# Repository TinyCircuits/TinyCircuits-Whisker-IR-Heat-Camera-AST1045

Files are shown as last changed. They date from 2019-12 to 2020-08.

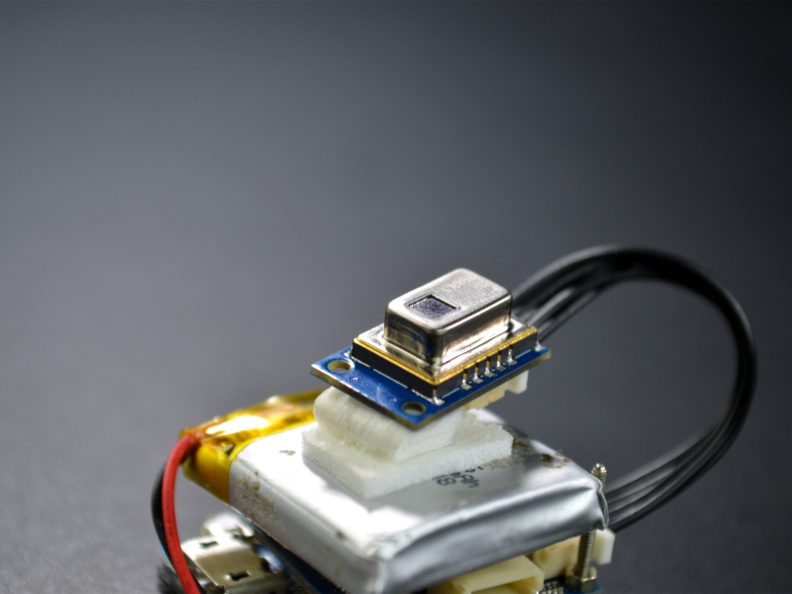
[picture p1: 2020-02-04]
images/AST1045-Tutorial-Image-01.jpg

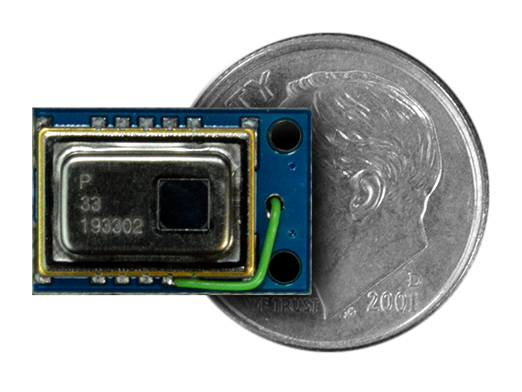
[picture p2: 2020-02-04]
images/AST1045-Product-Picture-03.png

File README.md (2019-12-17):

# TinyCircuits-Wireling-IR-Heat-Camera-AST1045
# Rev 1

The design files are located under design_files/ for the TinyCircuits AST1045 Rev 1 PCB. This is a Wireling board which features an IR thermal Camera using the AMG8833 IR Array Gird-EYE Sensor.
Format is in Cadsoft Eagle format - Eagle version 6.2 was used for the original design.

For more infomation on this, check out the product page at TinyCircuits.com

# License:

Design by TinyCircuits.
All design files are released under the Creative Commons Attribution Share-Alike 3.0 License, see the following link for details: http://creativecommons.org/licenses/by-sa/3.0

All text above must be included in any redistribution or derived design

This project uses designs and concepts developed as part of the Arduino project and the LilyPad project.  The TinyCircuits design files themselves (schematics, PCB and libraries) are not directly derived from these works' design files and have been created new, however the concepts and basic architecture behind the TinyDuino and TinyLily products are derived and we thank the hard work of the organizations below for their contributions to open-source hardware:
  
Original Arduino Uno Design by Team Arduino

LilyPad Arduino Design by Leah Buechley and Sparkfun Electronics

Please support the open-source hardware community

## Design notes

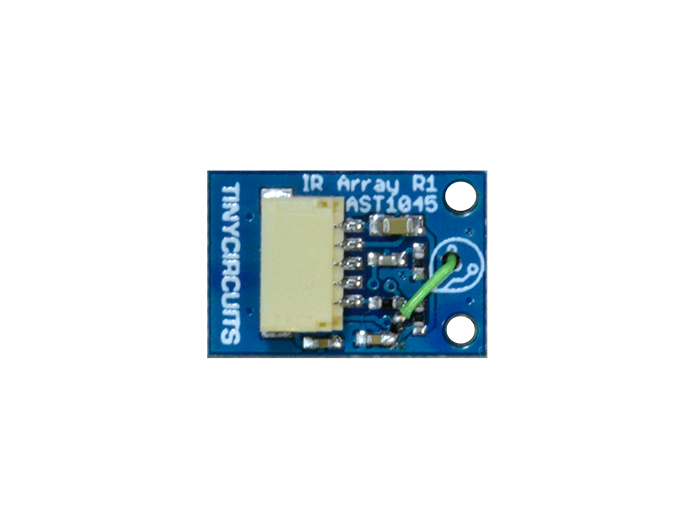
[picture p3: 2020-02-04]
images/AST1045-Product-Picture-02.png

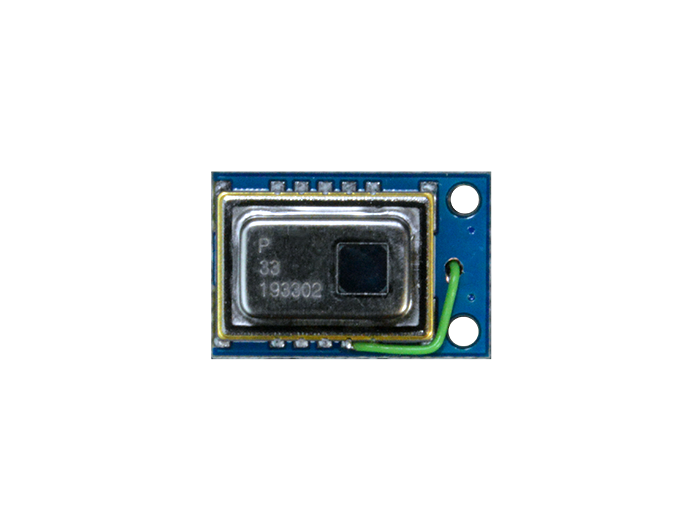
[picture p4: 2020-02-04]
images/AST1045-Product-Picture-01.png

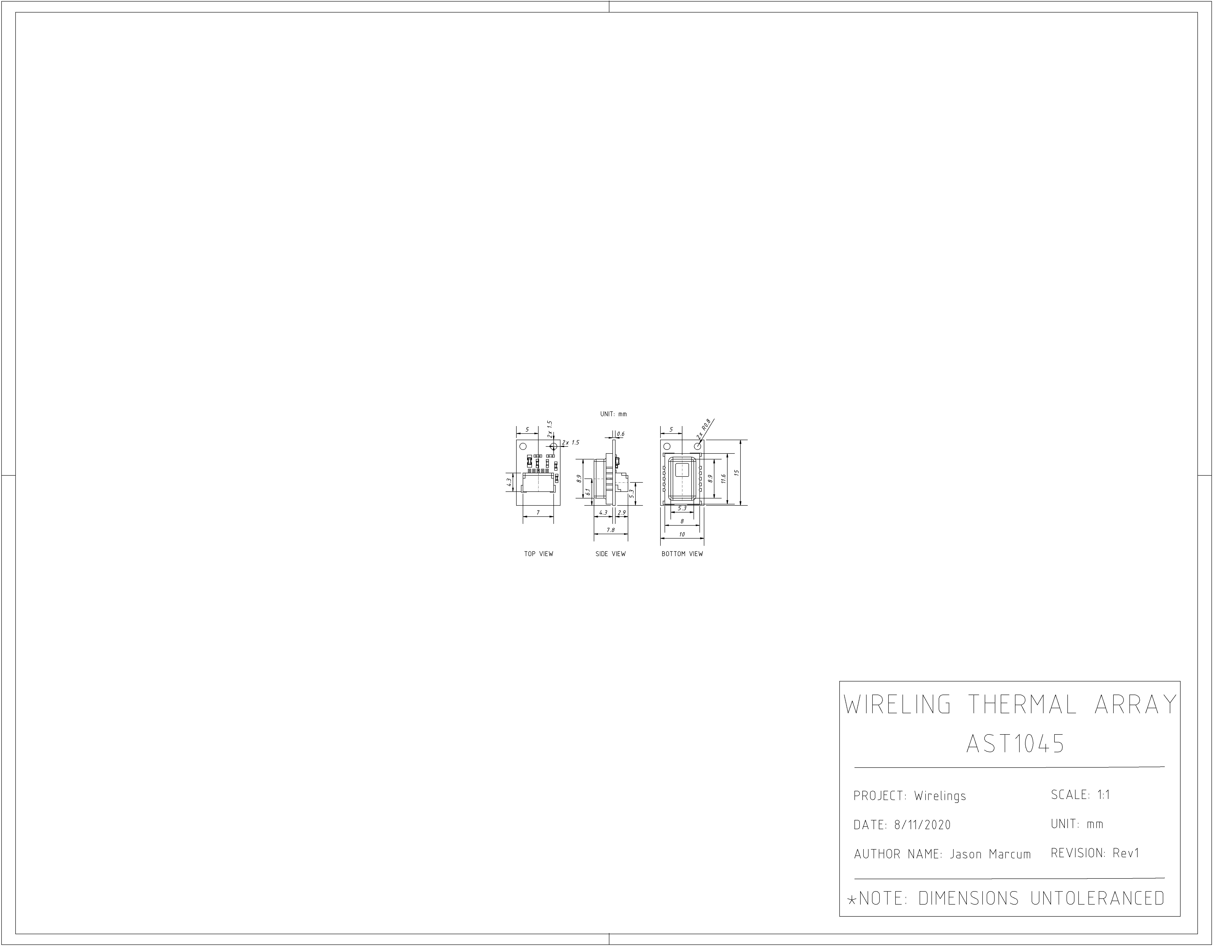
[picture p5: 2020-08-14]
cad/Wireling_THRMERAL_AST1045_REV1-DETAILED_DRAWING-PNG.png

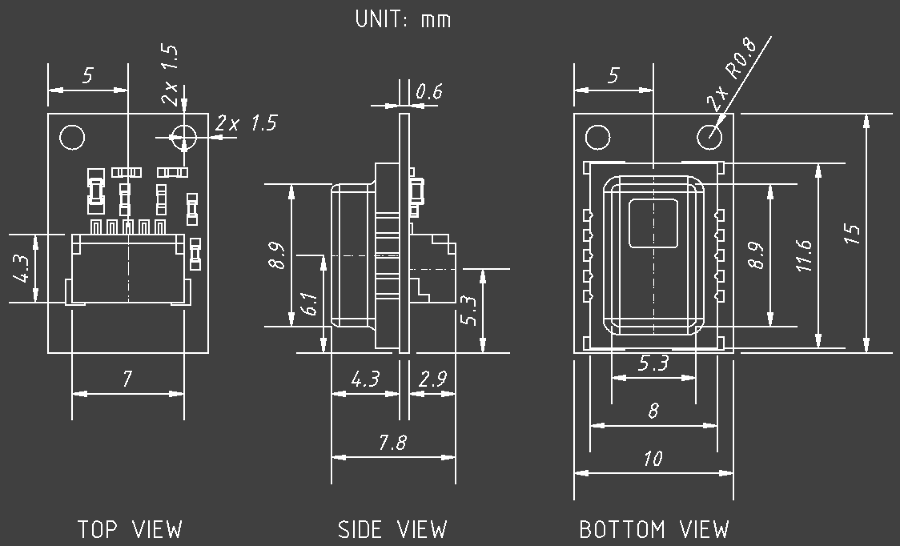
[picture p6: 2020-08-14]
cad/Wireling_THRMERAL_AST1045_REV1-DETAILED_DRAWING_COMPACT-PNG.png

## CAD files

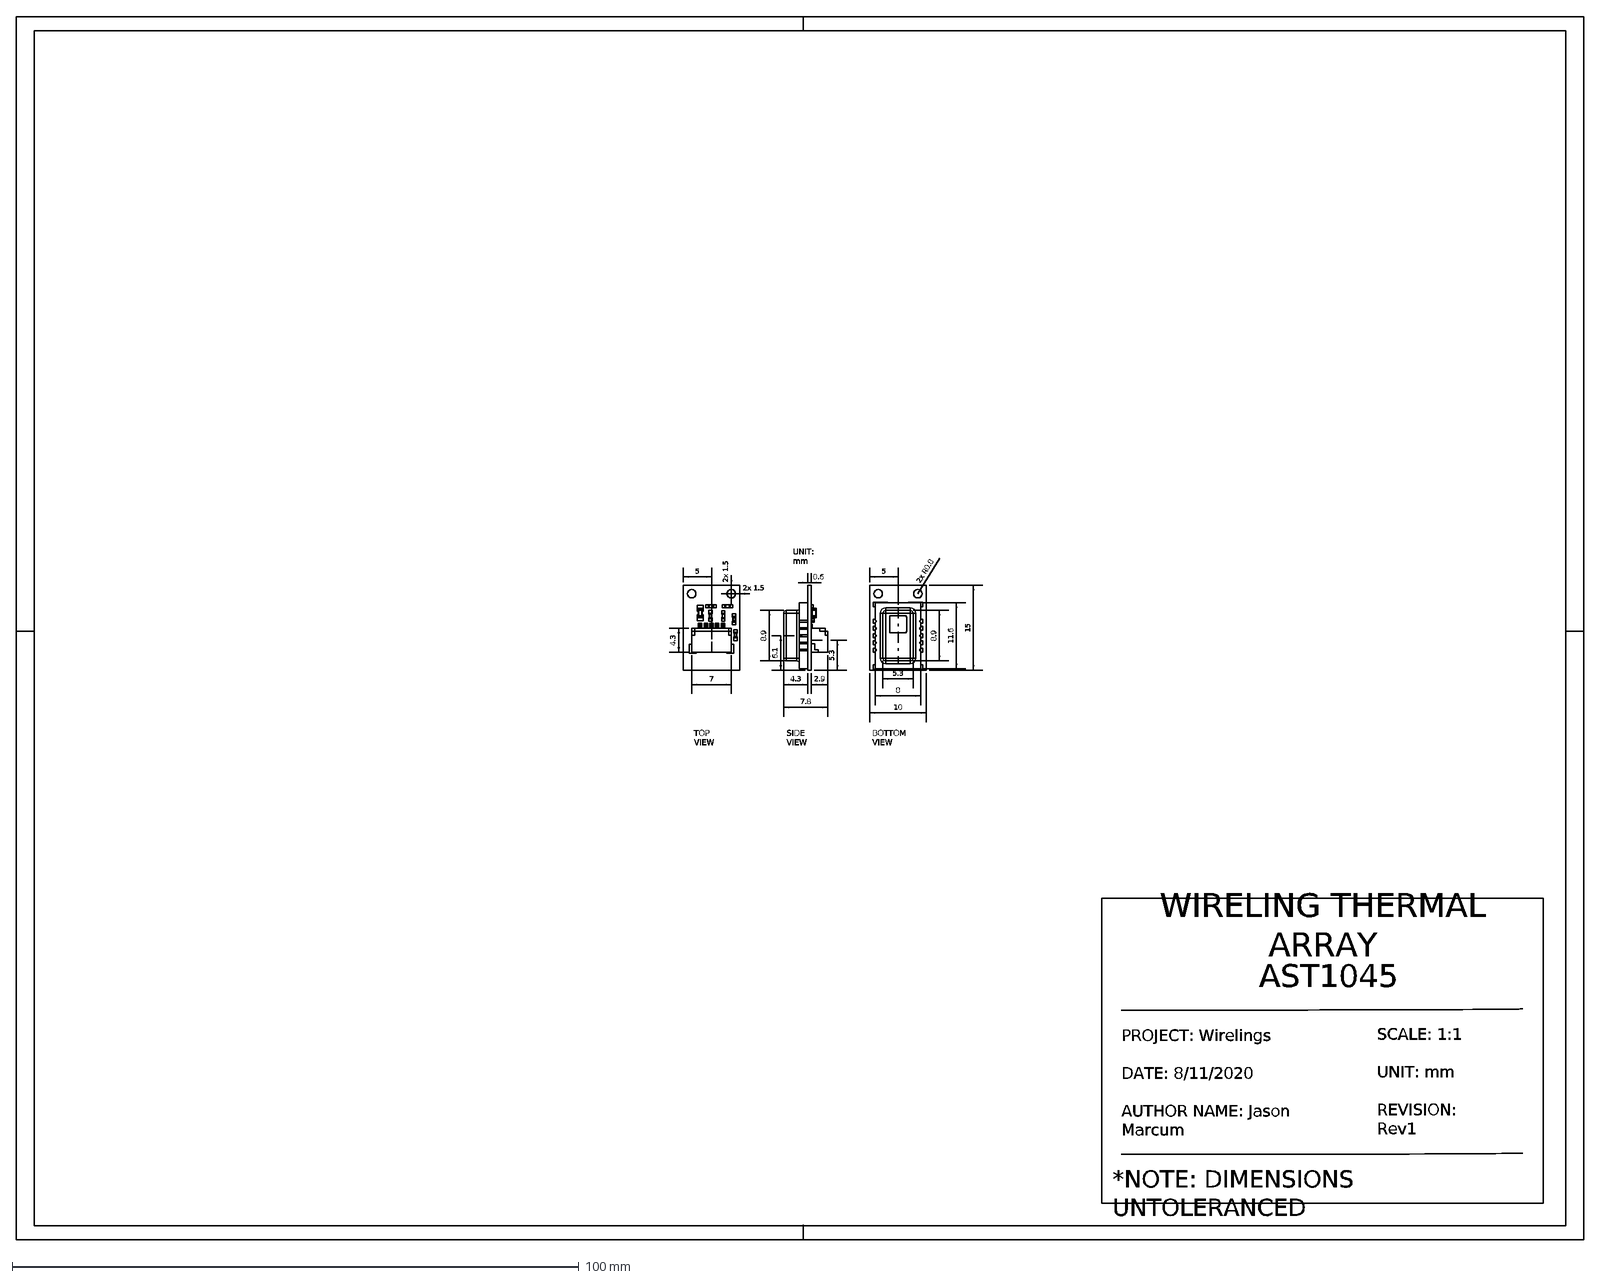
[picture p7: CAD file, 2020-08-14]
cad/Wireling_THRMERAL_AST1045_REV1-DETAILED_DRAWING-DXF.dxf
*NOTE: DIMENSIONS UNTOLERANCED
SCALE: 1:1 UNIT: mm REVISION: Rev1
5.3
6.1
2.9
4.3
0.6
SIDE VIEW
WIRELING THERMAL ARRAY
AST1045
PROJECT: Wirelings DATE: 8/11/2020 AUTHOR NAME: Jason Marcum
7.8
8.9
5
7
TOP VIEW
2x 1.5
8
11.6
15
10
BOTTOM VIEW
2x R0.8
UNIT: mm

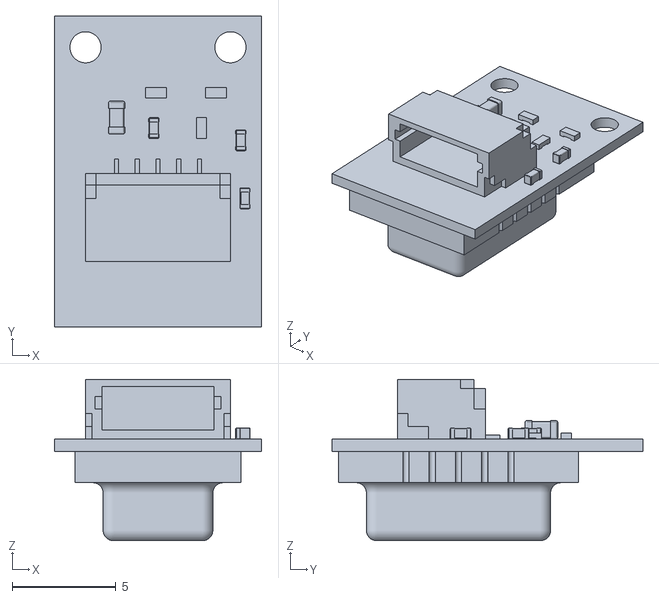
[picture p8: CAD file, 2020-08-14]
cad/Wireling_THRMERAL_AST1045_REV1-STL.stl
10.0 x 15.0 x 7.80

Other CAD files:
cad/Wireling_THRMERAL_AST1045_REV1-IGES.iges

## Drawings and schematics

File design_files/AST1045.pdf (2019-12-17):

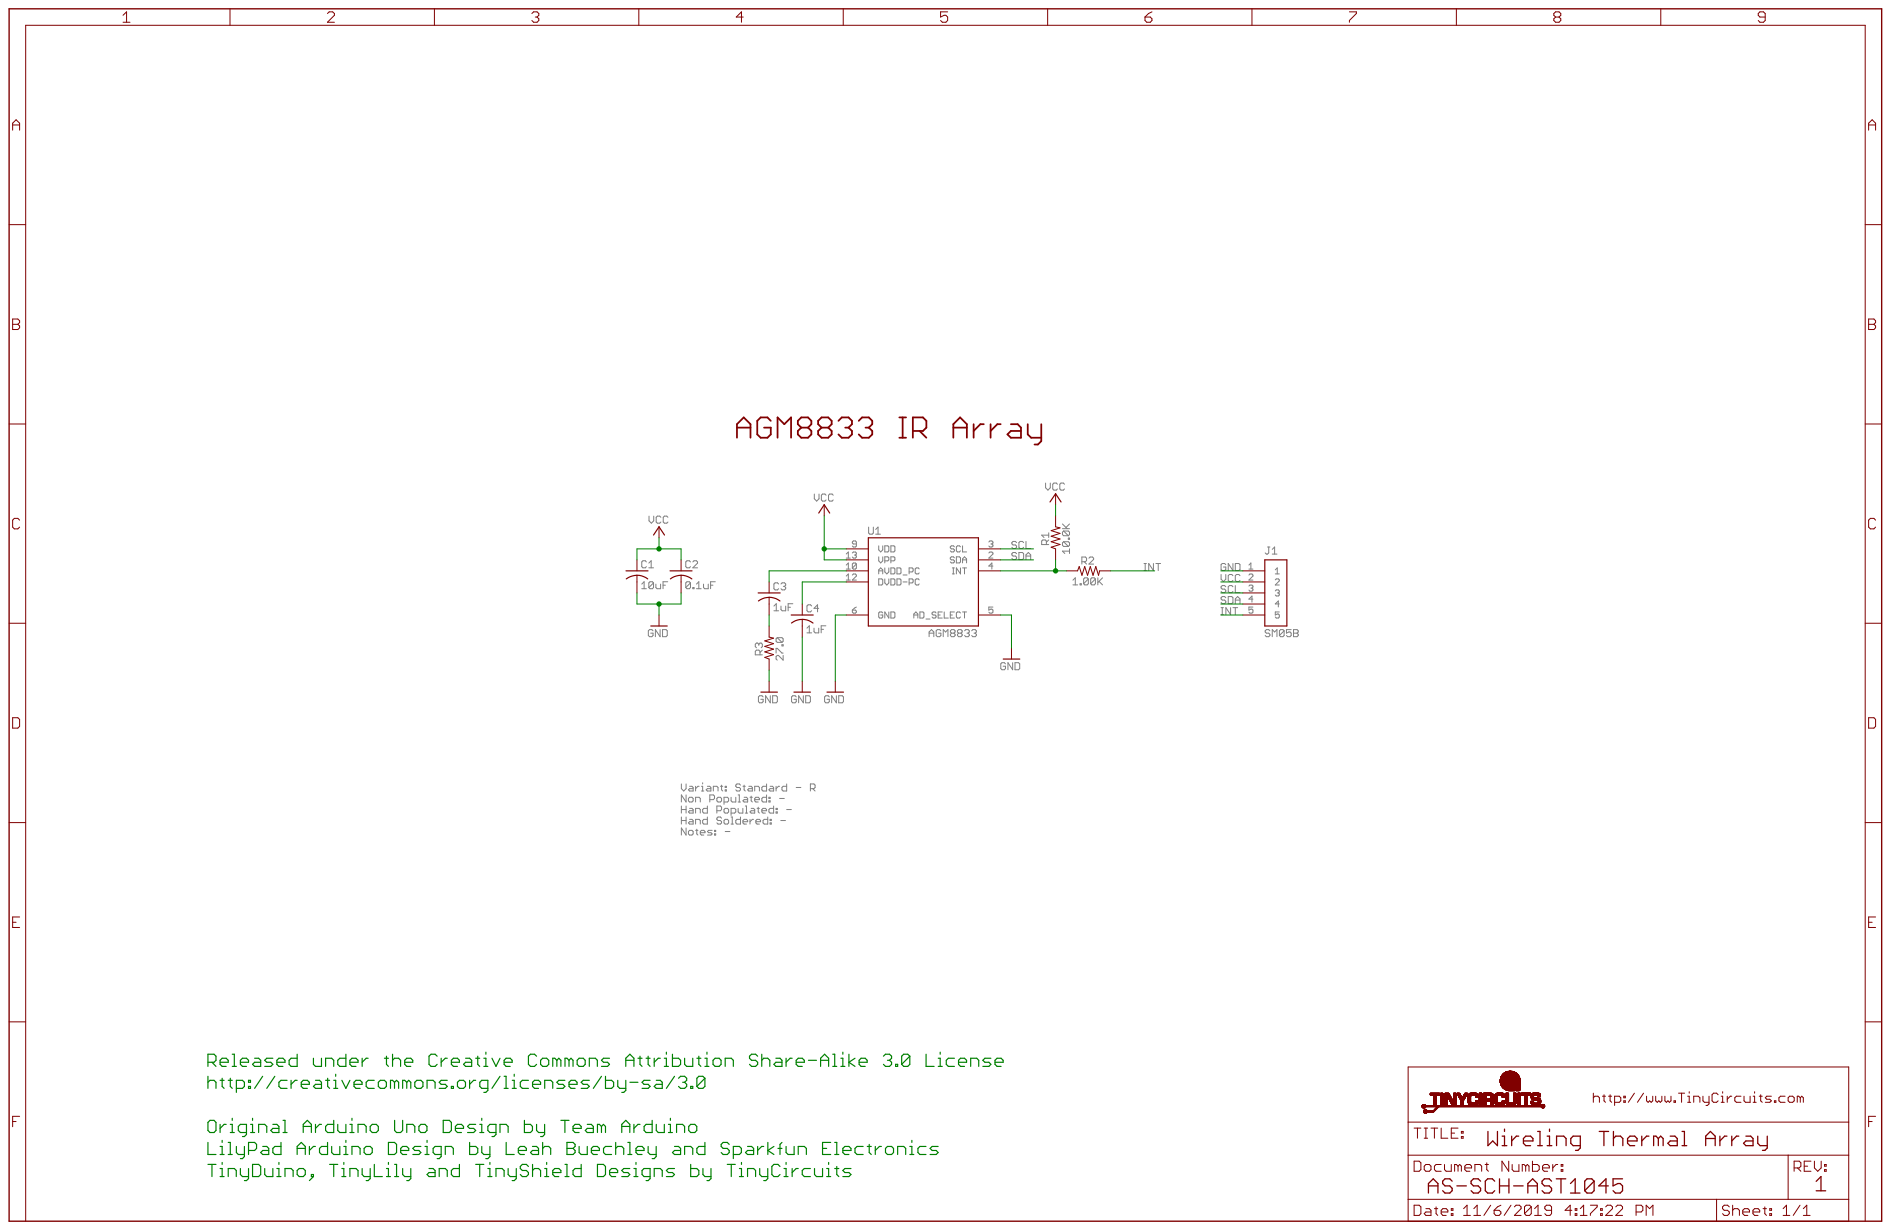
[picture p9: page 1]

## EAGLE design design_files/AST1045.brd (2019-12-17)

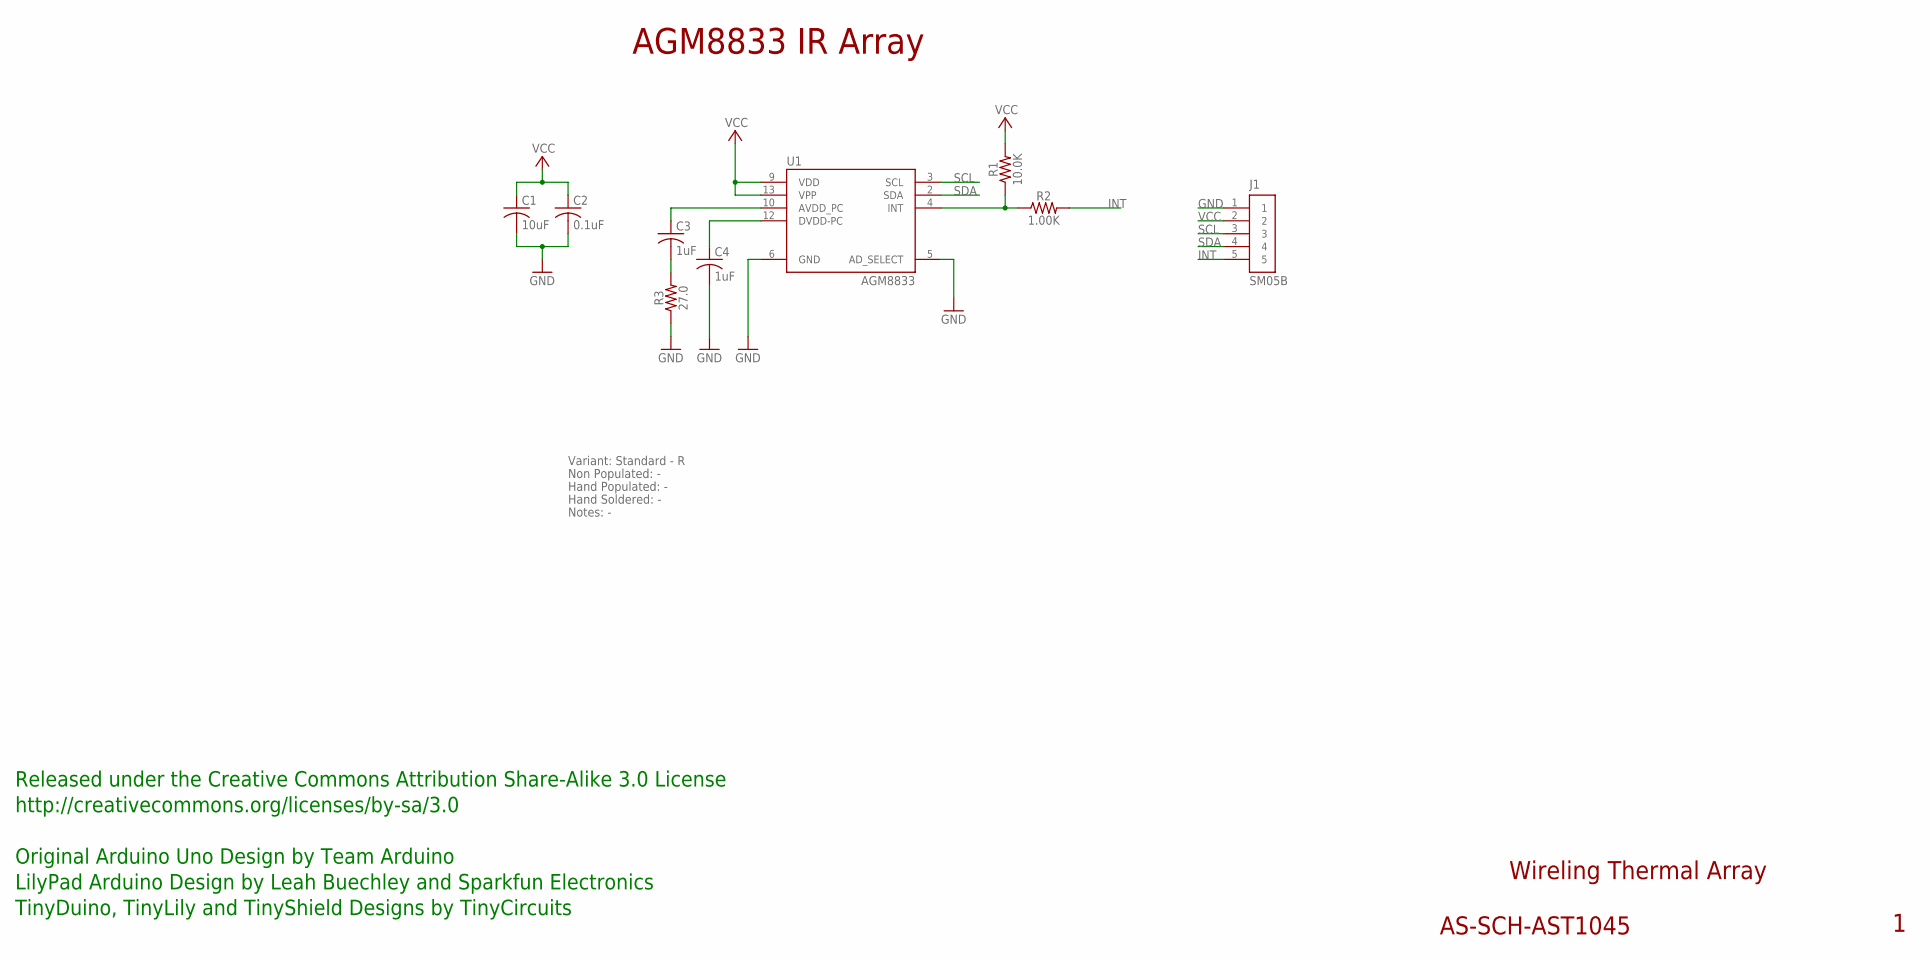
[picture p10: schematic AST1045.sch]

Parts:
C1: 10uF; C0603
C2: 0.1uF; C0402
C3: 1uF; C0402
C4: 1uF; C0402; PARTNO AS-ITM-00105
J1: SM05B; JST_SH_5X1
R1: 10.0K; 0402; PARTNO AS-ITM-00032
R2: 1.00K; 0402; PARTNO AS-ITM-00003
R3: 27.0; 0402
U1: AGM8833; AMG8833

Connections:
GND: C1.2, C2.2, C4.2, J1.1, R3.1, U1.5 (AD_SELECT), U1.6 (GND)
INT: J1.5, R2.2
unnamed: C3.1, U1.10 (AVDD_PC)
unnamed: C3.2, R3.2
unnamed: C4.1, U1.12 (DVDD-PC)
unnamed: R1.1, R2.1, U1.4 (INT)
SCL: J1.3, U1.3 (SCL)
SDA: J1.4, U1.2 (SDA)
VCC: C1.1, C2.1, J1.2, R1.2, U1.9 (VDD), U1.13 (VPP)

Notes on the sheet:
Wireling Thermal Array
AS-SCH-AST1045
AGM8833 IR Array
Released under the Creative Commons Attribution Share-Alike 3.0 License
http://creativecommons.org/licenses/by-sa/3.0
Original Arduino Uno Design by Team Arduino
TinyDuino, TinyLily and TinyShield Designs by TinyCircuits
LilyPad Arduino Design by Leah Buechley and Sparkfun Electronics
Non Populated: -
Hand Populated: -
Hand Soldered: -
Variant: Standard - R
Notes: -

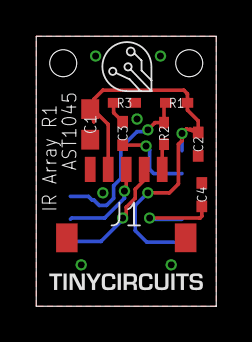
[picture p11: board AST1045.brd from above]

Board: 2 copper layers, 10.0 x 15.0 mm, 10 parts (1 on the bottom side), 9 nets.

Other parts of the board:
U$1: DOCFIELD-TINYCIRCUITS-PCB

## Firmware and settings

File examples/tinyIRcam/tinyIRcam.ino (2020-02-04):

//////////////////////////////////////////////////
/// tinyscreen+ amg88 thermal camera
/// (C) 2018 JAMcInnes, Use freely for any purpose
///
/// based on some example code found at adafruit, tinyscreen, and other

#include <Wire.h>
#include <Adafruit_AMG88xx.h>
#include <TinyScreen.h> 

// tinyscreen stuff
TinyScreen display = TinyScreen(TinyScreenPlus);

// grideye stuff
Adafruit_AMG88xx amg;
float irdata[ AMG88xx_PIXEL_ARRAY_SIZE ];
const int AMG88xx_HEIGHT = 8;
const int AMG88xx_WIDTH = 8;

// ir bitmap
const int bmp_scale = 2;
const int bmp_width = AMG88xx_HEIGHT * bmp_scale;
const int bmp_height = AMG88xx_WIDTH * bmp_scale;
//uint8_t bmp[ bmp_width * bmp_height ]; <--don't need this anymore

// offscreen buffer
const int obuf_dim = 64;
uint8_t obuf[ obuf_dim * obuf_dim ];

/// a temperature to color mapping helper
struct AMapColor
{
  float val;
  uint8_t r, g, b; // 8bit R G B

  uint8_t Color8()
  {
    return Color8( r, g, b );
  }

  static uint8_t Color8( uint8_t rin, uint8_t gin, uint8_t bin )
  {
    // packed 8 bit 332 BGR
    uint8_t bb = bin >> 5;
    uint8_t gg = gin >> 5;
    uint8_t rr = rin >> 6;
    uint8_t col8 = (bb << 5) | (gg << 2) | rr;
    return col8;
  }
};

/// a color map is an array of amapcolors
// colorful
AMapColor gMap0[] =
{
  { -10, 0, 0, 0 },
  { 0, 20, 0, 20 },
  { 24, 0, 0, 120 },
  { 27, 0, 240, 0 },
  { 34, 255, 255, 0 },
  { 42, 255, 0, 0 },
  { 65, 255, 50, 50 },
  { 80, 255, 190, 190 }
};

// low range blue
AMapColor gMap1[] =
{
  { -10, 0, 0, 15 },
  { 0, 0, 0, 255 },
  { 20, 0, 100, 255 },
  { 40, 0, 255, 255 }
};

// high range red
AMapColor gMap2[] =
{
  { 20, 15, 0, 0 },
  { 80, 255, 0, 0 },
  { 120, 255, 120, 0 }
};

// array of colormaps
struct AMap
{
  AMapColor *col_array;
  int num_col;
};

AMap gMapArray[] =    // eeccch this is getting ugly
{
  { gMap0, sizeof(gMap0)/sizeof(AMapColor) },
  { gMap1, sizeof(gMap1)/sizeof(AMapColor) },
  { gMap2, sizeof(gMap2)/sizeof(AMapColor) }
};
const int CMAPARRAY_SIZE = sizeof(gMapArray)/sizeof(AMap);
int gCMapIdx = 0; // this is a user control

// some user controls
bool gfEmphasis = true;

enum
{
  INTERPOLATION_NEAREST = 0,
  INTERPOLATION_BILINEAR,
  INTERPOLATION_BICUBIC
};
const int INTERPOLATION_MAX = 2;
int gInterpolation = INTERPOLATION_BILINEAR;


float GetIRPixel( int px, int py )
{ 
  // reverse x 
  px = AMG88xx_WIDTH - 1 - px;
  
  if ( px < 0 )
    px = 0;
  else if ( px >= AMG88xx_WIDTH )
    px = AMG88xx_WIDTH - 1;

  // we'll just go with Y as it is.. not much help in datasheet
  // ..or on web.
  if ( py < 0 )
    py = 0;
  else if ( py >= AMG88xx_HEIGHT )
    py = AMG88xx_HEIGHT - 1;
    
  return irdata[ py * AMG88xx_HEIGHT + px ]; // column order?
}

/*
float mapf(float x, float in_min, float in_max, float out_min, float out_max)
{
  return (x - in_min) * (out_max - out_min) / (in_max - in_min) + out_min;
}
*/

float SampleBilinear( float u, float v )
{
  float x = (u * (AMG88xx_WIDTH-1));// - 0.5f;
  int xi = int(x);
  float x_frac = x - floor(x);
  
  float y = (v * (AMG88xx_HEIGHT-1));// - 0.5f;
  int yi = int(y);
  float y_frac = y - floor(y);

  float inv_y_frac = 1.0f - y_frac;
  float inv_x_frac = 1.0f - x_frac;

  float c0 = GetIRPixel( xi, yi );
  float c1 = GetIRPixel( xi+1, yi );
  float c2 = GetIRPixel( xi+1, yi+1 );
  float c3 = GetIRPixel( xi, yi+1 );

  float tc = c0 * inv_y_frac * inv_x_frac +
      c1 * inv_y_frac * x_frac +
      c2 * y_frac * x_frac +
      c3 * y_frac * inv_x_frac;

  return tc;
}

// t is a value that goes from 0 to 1 to interpolate in a C1 continuous way across uniformly sampled data points.
// when t is 0, this will return B.  When t is 1, this will return C.  Inbetween values will return an interpolation
// between B and C.  A and B are used to calculate slopes at the edges.
float CubicHermite (float A, float B, float C, float D, float t)
{       
  float a = -A / 2.0f + (3.0f*B) / 2.0f - (3.0f*C) / 2.0f + D / 2.0f;
  float b = A - (5.0f*B) / 2.0f + 2.0f*C - D / 2.0f;
  float c = -A / 2.0f + C / 2.0f;
  float d = B;
  return a*t*t*t + b*t*t + c*t + d;
}

float SampleBicubic ( float u, float v )
{       
  float x = (u * (AMG88xx_WIDTH-1));
  int xi = int(x); 
  float x_frac = x - floor(x);

  float y = (v * (AMG88xx_HEIGHT-1));
  int yi = int(y); 
  float y_frac = y - floor(y);

  // 1st row 
  float p00 = GetIRPixel( xi - 1, yi - 1);
  float p10 = GetIRPixel( xi + 0, yi - 1);
  float p20 = GetIRPixel( xi + 1, yi - 1);
  float p30 = GetIRPixel( xi + 2, yi - 1);
  // 2nd row 
  float p01 = GetIRPixel( xi - 1, yi + 0);
  float p11 = GetIRPixel( xi + 0, yi + 0);
  float p21 = GetIRPixel( xi + 1, yi + 0);
  float p31 = GetIRPixel( xi + 2, yi + 0);
  // 3rd row 
  float p02 = GetIRPixel( xi - 1, yi + 1);
  float p12 = GetIRPixel( xi + 0, yi + 1);
  float p22 = GetIRPixel( xi + 1, yi + 1);
  float p32 = GetIRPixel( xi + 2, yi + 1);
  // 4th row 
  float p03 = GetIRPixel( xi - 1, yi + 2);
  float p13 = GetIRPixel( xi + 0, yi + 2);
  float p23 = GetIRPixel( xi + 1, yi + 2);
  float p33 = GetIRPixel( xi + 2, yi + 2);

  // bicubic interpolation
  float col0 = CubicHermite( p00, p10, p20, p30, x_frac );
  float col1 = CubicHermite( p01, p11, p21, p31, x_frac );
  float col2 = CubicHermite( p02, p12, p22, p32, x_frac );
  float col3 = CubicHermite( p03, p13, p23, p33, x_frac );
  float tc = CubicHermite( col0, col1, col2, col3, y_frac );

  return tc;
}

/// map a value to a color
uint8_t MapColor8( float val, int idx, AMap &cmap )
{  
  int max_col = cmap.num_col - 1;
  
  if( idx < 0 )
    return cmap.col_array[0].Color8();
  else if ( idx >= max_col )
    return cmap.col_array[ max_col ].Color8();

  AMapColor &mc0 = cmap.col_array[idx];
  AMapColor &mc1 = cmap.col_array[idx+1];

  uint8_t red = map( val, mc0.val, mc1.val, mc0.r, mc1.r );
  uint8_t green = map( val, mc0.val, mc1.val, mc0.g, mc1.g );
  uint8_t blue = map( val, mc0.val, mc1.val, mc0.b, mc1.b );

  return AMapColor::Color8( red, green, blue );
}

uint8_t TempToColor8( float temp_c, AMap &cmap )
{
  // search color map for temp_c
  uint8_t col = 0;
  for ( int i = 0; i < cmap.num_col; i++ )
  {
    if ( temp_c <= cmap.col_array[i].val )
    {
      col = MapColor8( temp_c, i-1, cmap );
      return col;
    }
  }

  // use last color in map
  col = MapColor8( temp_c, cmap.num_col-1, cmap );
  return col;
}

float ToFarenheit( float tc )
{
  return (tc * 9/5) + 32;
}

void setup()
{
  Wire.begin();
  SerialUSB.begin(9600);
  delay(50);
//  while (!SerialUSB);

  /// Setup for the TinyScreen
  display.begin();
  display.setBitDepth( TSBitDepth8 );
  display.setBrightness(12);  // 0 to 15
  display.setFlip(true);
  display.clearScreen();
  display.setFont( thinPixel7_10ptFontInfo );

  /// setup AMG
  // default settings
  bool fstatus = amg.begin();
  if ( !fstatus )
  {
    const char *err_msg = "No AMG88xx sensor!";
    display.println( err_msg );
    SerialUSB.println( err_msg );
    while (1);
  }

  delay(100); // let sensor boot up
}

void loop()
{ 
  AMap &cmap = gMapArray[ gCMapIdx ]; // get a reference to the current color map
  
  // which way is up on an amg88??
  // not sure what the intended orientation or order is here.. the amg datasheet
  // ..is ambiguous. same for project photos on the web.. we'll just go with
  // our own. see getirpixel()
  amg.readPixels( irdata );

  // find min and max temp
  float temp_min = 999999999;
  float temp_max = -999999999;
  for ( int i = 0; i < AMG88xx_PIXEL_ARRAY_SIZE; i++ )
  {
    if ( irdata[i] < temp_min )
      temp_min = irdata[i];
      
    if ( irdata[i] > temp_max )
      temp_max = irdata[i];
  }
  float temp_range = temp_max - temp_min;

  // bilinear blit irdata to bmp
  int o_scale = obuf_dim / bmp_width;  // uniform scale assumed
  for ( int by=0; by < bmp_height; by++ )
  {
    float pv = float(by) / float(bmp_height - 1);
    for ( int bx=0; bx < bmp_width; bx++ )
    {
      float pu = float(bx) / float(bmp_width - 1);

      // sample irdata
      float temp_c;
      if ( gInterpolation == INTERPOLATION_NEAREST )      
        temp_c = GetIRPixel( pu*AMG88xx_WIDTH, pv*AMG88xx_HEIGHT ); // nearest neighbor
      else if ( gInterpolation == INTERPOLATION_BILINEAR )
        temp_c = SampleBilinear( pu, pv );
      else if ( gInterpolation == INTERPOLATION_BICUBIC )
        temp_c = SampleBicubic( pu, pv );
      else
        temp_c = 0;

      // do emphasis?
      if ( gfEmphasis )
      {
        // square it
        float em = (temp_c - temp_min) / temp_range;
        em = em * em;
        temp_c = em * temp_range + temp_min;
      }
      else
      {
        temp_c = constrain( temp_c, temp_min, temp_max );
      }
      
      // do dynamic range?
      if ( false )
      {
        // fixme: map to current colormap, not just fixed 80C
        temp_c = (temp_c - temp_min) / temp_range * 80.0f;
      }

      uint8_t col = TempToColor8( temp_c, cmap );
//      bmp[ by * bmp_width + bx ] = col;
      // render direct to obuf
      uint8_t *pobuf_col = obuf + by * o_scale * obuf_dim;
      for ( int j = 0; j < o_scale; j++ )
      {
        uint8_t *pobuf_row = pobuf_col + bx * o_scale;
        pobuf_col += obuf_dim;
        for ( int i = 0; i < o_scale; i++ )
        {
          *(pobuf_row++) = col;
//          obuf[oy * obuf_dim + ox] = col;
        }
      }

    }
  }
/*
  // strech blit bmp to offscreen buffer
  int o_scale = obuf_dim / bmp_width;
  
  for ( int by=0; by < bmp_height; by++ )
  {
    for ( int bx=0; bx < bmp_width; bx++ )
    {
      uint8_t bmp_col = bmp[by * bmp_width + bx];      
      for ( int oy=by*o_scale; oy<(by+1)*o_scale; oy++ )
      {
        for ( int ox=bx*o_scale; ox<(bx+1)*o_scale; ox++ )
        {
          obuf[oy * obuf_dim + ox] = bmp_col;
        }
      }
    }
  }
*/

  // blit obuf to screen
  display.setX( 0, 0 + obuf_dim-1 );
  display.setY( 0, 0 + obuf_dim-1 );  
  display.startData();
  display.writeBuffer( obuf, obuf_dim * obuf_dim );
  display.endTransfer();

  // print min max temperature
  display.fontColor( TS_8b_Red, TS_8b_Black );
  display.setCursor( 65, 0 );
  display.print( "high:" );
  display.setCursor( 65, 10 );
  display.print( ToFarenheit( temp_max ), 1 );
  display.print( "F" );

  display.fontColor( TS_8b_Blue, TS_8b_Black );
  display.setCursor( 65, 20 );
  display.print( "low:" );
  display.setCursor( 65, 30 );
  display.print( ToFarenheit( temp_min ), 1 );
  display.print( "F" );

  // handle buttons
  DoInput();
  
  // print battery voltage & amg internal thermistor to serial
  float battVoltageReading = getBattVoltage();
  SerialUSB.print( battVoltageReading) ;
  SerialUSB.print("V battery, ");

  SerialUSB.print("thermistor ");
  SerialUSB.print( amg.readThermistor() );
  SerialUSB.println(" *C");
}

int CenterCursor( const char *msg )
{
  int mheight = display.getFontHeight();
  int mwidth = display.getPrintWidth( const_cast<char *>( msg ) );
  int cx = (display.xMax + 1)/2 - mwidth/2;
  int cy = (display.yMax + 1)/2 - mheight/2;
  display.setCursor( cx, cy );
}


void DoQuickMsg( const char *msg )
{
  // print the message and briefly pause, this also serves as a btn debounce
  display.fontColor( TS_8b_White, TS_8b_Black );
  CenterCursor( msg );
  display.print( msg );
  delay( 1000 );

  // clear everything to cleanup text
  display.clearScreen();
}

void DoInput()
{
  if ( display.getButtons(TSButtonUpperLeft) )
  {
    // cycle colormap
    if ( (++gCMapIdx) >= CMAPARRAY_SIZE )
    {
      gCMapIdx = 0;
    }
    DoQuickMsg( "colormap" );    
  }
  else if ( display.getButtons(TSButtonLowerLeft) )
  {
    // cycle emphasis on/off
    gfEmphasis = !gfEmphasis;    
    gfEmphasis ? DoQuickMsg( "emphasis on" ) : DoQuickMsg( "emphasis off" );
  }
  else if ( display.getButtons(TSButtonUpperRight) )
  {
    // cycle interpolation
    if ( (++gInterpolation) > INTERPOLATION_MAX )
    {
      gInterpolation = 0;
    }
    
    if ( gInterpolation == INTERPOLATION_NEAREST )
      DoQuickMsg( "nearest" );
    else if ( gInterpolation == INTERPOLATION_BILINEAR )
      DoQuickMsg( "bilinear" );
    else if ( gInterpolation == INTERPOLATION_BICUBIC )
      DoQuickMsg( "bicubic" );
  }

}

// This function gets the battery VCC internally, you can checkout this link 
// if you want to know more about how: 
// http://atmel.force.com/support/articles/en_US/FAQ/ADC-example
float getVCC()
{
  SYSCTRL->VREF.reg |= SYSCTRL_VREF_BGOUTEN;
  while (ADC->STATUS.bit.SYNCBUSY == 1);
  ADC->SAMPCTRL.bit.SAMPLEN = 0x1;
  while (ADC->STATUS.bit.SYNCBUSY == 1);
  ADC->INPUTCTRL.bit.MUXPOS = 0x19;         // Internal bandgap input
  while (ADC->STATUS.bit.SYNCBUSY == 1);
  ADC->CTRLA.bit.ENABLE = 0x01;             // Enable ADC
  while (ADC->STATUS.bit.SYNCBUSY == 1);
  ADC->SWTRIG.bit.START = 1;  // Start conversion
  ADC->INTFLAG.bit.RESRDY = 1;  // Clear the Data Ready flag
  while (ADC->STATUS.bit.SYNCBUSY == 1);
  ADC->SWTRIG.bit.START = 1;  // Start the conversion again to throw out first value
  while ( ADC->INTFLAG.bit.RESRDY == 0 );   // Waiting for conversion to complete
  uint32_t valueRead = ADC->RESULT.reg;
  while (ADC->STATUS.bit.SYNCBUSY == 1);
  ADC->CTRLA.bit.ENABLE = 0x00;             // Disable ADC
  while (ADC->STATUS.bit.SYNCBUSY == 1);
  SYSCTRL->VREF.reg &= ~SYSCTRL_VREF_BGOUTEN;
  float vcc = (1.1 * 1023.0) / valueRead;
  return vcc;
}

// Calculate the battery voltage
float getBattVoltage()
{
  const int VBATTpin = A4;
  float VCC = getVCC();

  // Use resistor division and math to get the voltage
  float resistorDiv = 0.5;
  float ADCres = 1023.0;
  float battVoltageReading = analogRead(VBATTpin);
  battVoltageReading = analogRead(VBATTpin); // Throw out first value
  float battVoltage = VCC * battVoltageReading / ADCres / resistorDiv;

  return battVoltage;
}

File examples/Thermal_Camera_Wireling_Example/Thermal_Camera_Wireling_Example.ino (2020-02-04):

/****************************************************************************
 * IR Array Thermal Camera Wireling Example
 * This Arduino sketch assumes the use of a TinyScreen+ processor being used
 * with a Thermal Camera Wireling plugged into Port 1 of a Wireling Adapter 
 * TinyShield. The program will display the 8x8 thermal array of temperatures 
 * ranging from MINTEMP degC (blue) to MAXTEMP degC (red).
 * 
 * Hardware by: TinyCircuits
 * Adapted from Adafruit Example by: Hunter Hykes for TinyCircuits
 * Initiated 8/07/19
 * Last updated 10/18/19
 ****************************************************************************/

#include <Wire.h>
#include <SPI.h>
#include <TinyScreen.h>
#include <Wireling.h>
#include <Adafruit_AMG88xx.h> 

TinyScreen display = TinyScreen(TinyScreenPlus);
uint8_t buffer[96 * 64 * 2];

Adafruit_AMG88xx amg; // thermal camera object

float pixels[AMG88xx_PIXEL_ARRAY_SIZE]; // data array from thermal camera
uint16_t displayPixelWidth, displayPixelHeight;

const uint8_t xCameraRes = 8;
const uint8_t yCameraRes = 8;

float minimum = 0x7F7FFFFF; // maximum value for a float
float maximum = -273.15; // absolute zero (you won't get this cold)

//low range of the sensor (this will be blue on the screen)
#define MINTEMP 0

//high range of the sensor (this will be red on the screen)
#define MAXTEMP 34

#define backgroundColor TS_16b_Black

//the colors we will be using
const uint16_t camColors[] = {0x480F,
0x400F,0x400F,0x400F,0x4010,0x3810,0x3810,0x3810,0x3810,0x3010,0x3010,
0x3010,0x2810,0x2810,0x2810,0x2810,0x2010,0x2010,0x2010,0x1810,0x1810,
0x1811,0x1811,0x1011,0x1011,0x1011,0x0811,0x0811,0x0811,0x0011,0x0011,
0x0011,0x0011,0x0011,0x0031,0x0031,0x0051,0x0072,0x0072,0x0092,0x00B2,
0x00B2,0x00D2,0x00F2,0x00F2,0x0112,0x0132,0x0152,0x0152,0x0172,0x0192,
0x0192,0x01B2,0x01D2,0x01F3,0x01F3,0x0213,0x0233,0x0253,0x0253,0x0273,
0x0293,0x02B3,0x02D3,0x02D3,0x02F3,0x0313,0x0333,0x0333,0x0353,0x0373,
0x0394,0x03B4,0x03D4,0x03D4,0x03F4,0x0414,0x0434,0x0454,0x0474,0x0474,
0x0494,0x04B4,0x04D4,0x04F4,0x0514,0x0534,0x0534,0x0554,0x0554,0x0574,
0x0574,0x0573,0x0573,0x0573,0x0572,0x0572,0x0572,0x0571,0x0591,0x0591,
0x0590,0x0590,0x058F,0x058F,0x058F,0x058E,0x05AE,0x05AE,0x05AD,0x05AD,
0x05AD,0x05AC,0x05AC,0x05AB,0x05CB,0x05CB,0x05CA,0x05CA,0x05CA,0x05C9,
0x05C9,0x05C8,0x05E8,0x05E8,0x05E7,0x05E7,0x05E6,0x05E6,0x05E6,0x05E5,
0x05E5,0x0604,0x0604,0x0604,0x0603,0x0603,0x0602,0x0602,0x0601,0x0621,
0x0621,0x0620,0x0620,0x0620,0x0620,0x0E20,0x0E20,0x0E40,0x1640,0x1640,
0x1E40,0x1E40,0x2640,0x2640,0x2E40,0x2E60,0x3660,0x3660,0x3E60,0x3E60,
0x3E60,0x4660,0x4660,0x4E60,0x4E80,0x5680,0x5680,0x5E80,0x5E80,0x6680,
0x6680,0x6E80,0x6EA0,0x76A0,0x76A0,0x7EA0,0x7EA0,0x86A0,0x86A0,0x8EA0,
0x8EC0,0x96C0,0x96C0,0x9EC0,0x9EC0,0xA6C0,0xAEC0,0xAEC0,0xB6E0,0xB6E0,
0xBEE0,0xBEE0,0xC6E0,0xC6E0,0xCEE0,0xCEE0,0xD6E0,0xD700,0xDF00,0xDEE0,
0xDEC0,0xDEA0,0xDE80,0xDE80,0xE660,0xE640,0xE620,0xE600,0xE5E0,0xE5C0,
0xE5A0,0xE580,0xE560,0xE540,0xE520,0xE500,0xE4E0,0xE4C0,0xE4A0,0xE480,
0xE460,0xEC40,0xEC20,0xEC00,0xEBE0,0xEBC0,0xEBA0,0xEB80,0xEB60,0xEB40,
0xEB20,0xEB00,0xEAE0,0xEAC0,0xEAA0,0xEA80,0xEA60,0xEA40,0xF220,0xF200,
0xF1E0,0xF1C0,0xF1A0,0xF180,0xF160,0xF140,0xF100,0xF0E0,0xF0C0,0xF0A0,
0xF080,0xF060,0xF040,0xF020,0xF800,};

uint8_t dispColors[AMG88xx_PIXEL_ARRAY_SIZE]; // used to store 8x8 grid of colors to display (*2 since actually 16-bit)

int pixelSize;
int xMax = display.xMax;
int yMax = display.yMax;

void setup() {
  Wire.begin();
  Wireling.begin();
  display.begin();
  display.setBrightness(10);
  display.clearScreen();
  display.setFlip(0);
  display.setBitDepth(TSBitDepth16);
  
  displayPixelWidth = yMax / yCameraRes;
  displayPixelHeight = xMax / xCameraRes;

  pixelSize = findPixelSize(xMax, yMax);
  
  Wireling.selectPort(1);
  delay(100); // let sensor boot up
  amg.begin();
  
}

void loop() {
  amg.readPixels(pixels);
  getMinMax();
  drawBuffer();
}

void getMinMax() {
  minimum = 0x7F7FFFFF; // maximum value for a float
  maximum = -273.15; // absolute zero (you won't get this cold)
  
  for(int i = 0; i < AMG88xx_PIXEL_ARRAY_SIZE; i++) {
    float val = pixels[i];
    if(val > maximum)
      maximum = val;
    if(val < minimum)
      minimum = val;
  }

  float range = maximum - minimum;
  int minimumRange = 7;
  if(range < minimumRange) {
    minimum += (minimumRange - (maximum-minimum)) / 2;
    maximum += (minimumRange - (maximum-minimum)) / 2;
  }
}

// part of the color workaround
uint16_t convertColor(uint16_t original) {
  uint16_t converted = 0x0000;

  converted |= (original & 0xF800) >> 11; // RED
  converted |= (original & 0x07E0);       // GREEN
  converted |= (original & 0x001F) << 11; // BLUE

  return converted;
}

//"pixels" on display will be n by n pixels, where n is the returned value
int findPixelSize(int screenXwidth, int screenYheight) {
  if(screenXwidth == screenYheight) { // screen is a square (convenient!)
    return screenXwidth / xCameraRes; // 8 is from the 8x8 thermal camera resolution
  } else if(screenXwidth < screenYheight){
    return screenXwidth / xCameraRes;
  } else {
    return screenYheight / yCameraRes;
  }
}

void drawBuffer() {                             //populates the buffer, then writes it to the screen
  for (int i = 0; i < 64 * 96; i++) {           //For every pixel in the buffer, write the background color first
    buffer[i * 2] = backgroundColor >> 8;
    buffer[i * 2 + 1] = backgroundColor;
  }

  //puts specified string into the buffer in the font and colors specified at the given coordinates
  putImage();

  display.goTo(0, 0);
  display.startData();                          //Activates the OLED driver chip to ready it for receiving commands (drives CS line HIGH)
  display.writeBuffer(buffer, 96 * 64 * 2);     //Write all of the pixel data (saved in buffer) to the screen (update what is being displayed on screen)
  display.endTransfer();                        //Deactivate the OLED driver chip now that it has been updated (drives CS pin LOW)
}
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

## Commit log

2019-12-17 updated documentation
    [AST1045.brd, AST1045.sch]
2020-08-14 Add CAD data
    [Wireling_THRMERAL_AST1045_REV1-DETAILED_DRAWING-DXF.dxf, Wireling_THRMERAL_AST1045_REV1-IGES.iges, Wireling_THRMERAL_AST1045_REV1-STL.stl]
